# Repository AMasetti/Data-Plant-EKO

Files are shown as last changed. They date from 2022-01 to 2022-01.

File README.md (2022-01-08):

# Data Plant EKO

This project aims to have a plant pot fitted with electronics capable of monitoring a plant and alerting it’s owned if some parameter they see fit are out of certainty bounds. The captured data from the ambient and the plant is streamed to an MQTT Broker for later treatment if the MQTT option is enabled. This means the plant works as a stand alone unit monitoring and alerting the used via Neopixel lights or it can work in tandem with other systems streaming it’s data and listening for configuration changes

## Variables meassured

The following variables are measured and have a default lower and upper bound indicating the acceptable contritions that the plant need for it’s life to continue:

- Ambient Temperature [ºC]
    - Hardware: DHT11
    - Operating range: 0 - 50
    - Alerting range: <10 or >35

- Ambient Humidity [%]
    - Hardware: DHT11
    - Operating range: 0 - 100
    - Alerting range: <30 or >80

- Plant soil Temperature [ºC]
    - Hardware: NTC 3950
    - Operating range: :-20 - 105
    - Alerting range: <10 or >35

- Plant soil Humidity [%]
    - Hardware: HL-69
    - Operating range: 0 - 100
    - Alerting range: <30 or >80

- Ambient light [Lux]
    - Hardware: TEMP6000
    - Operating range: 0 -1000
    - Alerting range: 500

## Hardware used



The main CPU of the project is the ESP32 a microcontroller with integrated WiFi that is widely used in IoT projects. For fast prototyping and ease of repair the package used is the the Node MCU version of the ESP chip, which has breakout pins that can be easily soldered. 

The hardware used for the sensors is listed above with the corresponding variable measured.

No internal power supply is used in this project but the concept contemplates future improvements such as that. The electronics are powered by a micro usb connected directly to the Node MCU using a usb power plug as power source.

The soil sensors are fitted from under the pot and are isolated using hot glue to prevent water getting into the electronics. The ambient and light sensors are fitted on the side and top of the pot respectively. The Node MCU and Neopixel ring are located a the bottom of the pot. The pot on the other hand is made out of 3D printed transparent PLA which allows the Neopixel ring to light it out from the inside. This STLs files are provided in the Hardware folder of the project.

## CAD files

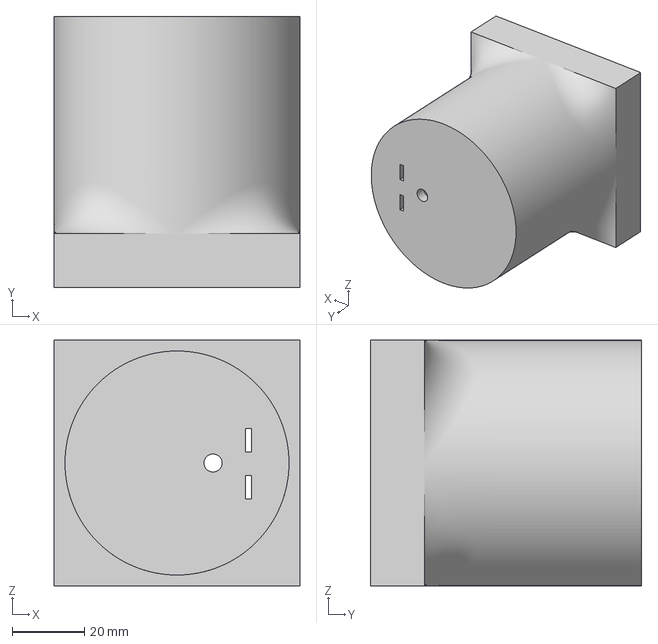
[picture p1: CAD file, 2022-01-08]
stls/MainPot.3mf
68.0 x 75.0 x 68.0 mm

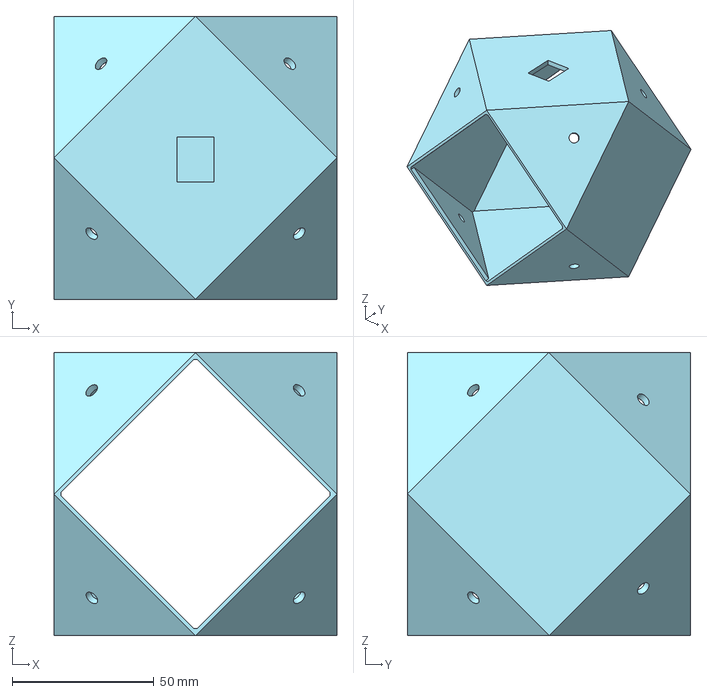
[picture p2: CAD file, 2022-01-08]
stls/CubeoctahedronShell.3mf
99.9 x 99.9 x 99.9 mm

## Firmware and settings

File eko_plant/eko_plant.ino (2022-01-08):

#include <Adafruit_Sensor.h>
#include <FastLED.h>
#include <DHT.h>
#include <WiFi.h>
#include <PubSubClient.h>
#include "secrets.h"

// MQTT Device ID definitions
#define DEVICE "eko"          // Device Name DataPlantEKO
#define ROOT "iotplant"       // MQTT Topic root

// Pin definitions
#define DHTPIN 26             // Digital pin connected to the DHT sensor
#define NUM_LEDS 8            // Number of LEDs in the strip
#define NEOPIN 25             // PWM Pin for the Neopixel ring
#define BRIGHTNESS  100       // Brightness of the LED strip
#define LIGHTSENSORPIN 39     // Ambient light sensor pin
#define SOILHUMPIN 36         // Soil humidity sensor pin

// Sensors definitions
#define DHTTYPE DHT11          // DHT 11 type of sensor in use (11, 21, 22)

// Client declarations
WiFiClient espClient;
PubSubClient client(espClient);
long lastMsg = 0;
char msg[100];
int value = 0;

// Hardware declarations
DHT dht(DHTPIN, DHTTYPE);
CRGB leds[NUM_LEDS];

// MQTT Topics definitions
String topic_root =  String(ROOT) + "/" + String(DEVICE);
// Data topic
String publish_data_str = topic_root + "/data";
const char* publish_data = publish_data_str.c_str();
// Configurations topic
String subs_config_str = topic_root + "/config";
const char* subs_config = subs_config_str.c_str();
// Neopixel status topic
String subs_neopixels_str = topic_root + "/neopixels";
const char* subs_neopixels = subs_neopixels_str.c_str();
// Reset alert topic
String publish_reset_string = topic_root + "/reset";
const char* publish_reset = publish_reset_string.c_str();

// NTP
const char* ntpServer = "pool.ntp.org";
unsigned long epochTime; 

// Plant configuration variables
bool enableMQTT = true;           // Sets the MQTT Client to ON by default
int sample_time = 500;            // Sample time in milliseconds
float minTempDHT = 0;             // Minimum temperature to be considered as a healthy plant (celsius)
float maxTempDHT = 50;            // Maximum temperature to be considered as a healthy plant (celsius)
float minHumDHT  = 0;             // Minimum humidity to be considered as a healthy plant (percentage)
float maxHumDHT  = 100;           // Maximum humidity to be considered as a healthy plant (percentage)
float minLight = 0;               // Minimum light to be considered as a healthy plant (percentage)
float maxLight = 100;             // Maximum light to be considered as a healthy plant (percentage)
float minSoilHum = 0;             // Minimum soil humidity to be considered as a healthy plant (percentage)
float maxSoilHum = 100;           // Maximum soil humidity to be considered as a healthy plant (percentage)
float minSoilTemp = 0;            // Minimum soil temperature to be considered as a healthy plant (celsius)
float maxSoilTemp = 50;           // Maximum soil temperature to be considered as a healthy plant (celsius)


unsigned long getTime() {
  time_t now;
  struct tm timeinfo;
  if (!getLocalTime(&timeinfo)) {
    //Serial.println("Failed to obtain time");
    return(0);
  }
  time(&now);
  return now;
}

void setup_wifi() {
  delay(10);
  // We start by connecting to a WiFi network
  Serial.println();
  Serial.print("Connecting to ");
  Serial.println(SSID);

  WiFi.begin(SSID, PASSWORD);

  while (WiFi.status() != WL_CONNECTED) {
    delay(500);
    Serial.print(".");
  }

  Serial.println("");
  Serial.println("WiFi connected");
  Serial.println("IP address: ");
  Serial.println(WiFi.localIP());
}

void callback(char* topic, byte* payload, unsigned int length) {
  Serial.print("Message arrived [");
  Serial.print(topic);
  Serial.print("] ");
  for (int i = 0; i < length; i++) {
    Serial.print((char)payload[i]);
  }
  Serial.println();

  if (String(topic) == String(subs_neopixels)) {
    // Switch on the LED if an 1 was received as first character
    if ((char)payload[0] == '1') {
//      fill_solid( leds, NUM_LEDS, CRGB::Black);
//      delay(50);
//      FastLED.show();
//      delay(50);
      // but actually the LED is on; this is because
      // it is active low on the ESP-01)
    } else {

//      fill_solid( leds, NUM_LEDS, CRGB::Blue);
//      delay(50);
//      FastLED.show();
//      delay(50);
    }
  }
}

void neo_wait() {
  // Flash LEDs in a circle with dimming brightness
  for (int i = 0; i < NUM_LEDS; i++) {
    leds[i] = CRGB::Blue;
    FastLED.show();
    delay(50);
    leds[i] = CRGB::Black;
    FastLED.show();
    delay(50);
  }
}

void neo_ok() {
  // pulsate the LEDs
  fill_solid( leds, NUM_LEDS, CRGB::Green);
  for (int i = 0; i < 100; i++) {
    FastLED.setBrightness(i);
    FastLED.show();
    delay(10);
  }
  fill_solid( leds, NUM_LEDS, CRGB::Black);
  FastLED.show();
  for (int i = 100; i > 0; i--) {
    FastLED.setBrightness(i);
    FastLED.show();
    delay(10);
  }
  fill_solid( leds, NUM_LEDS, CRGB::Black);
  FastLED.show();
}

void reconnect() {
  // Loop until we're reconnected
  while (!client.connected()) {
    Serial.print("Attempting MQTT connection...");
    // Attempt to connect
    if (client.connect("ESP32Client")) {
      Serial.println("connected");
      // Subscribe
      client.subscribe(subs_neopixels);
     client.subscribe(subs_config);
    } else {
      Serial.print("failed, rc=");
      Serial.print(client.state());
      Serial.println(" try again in 5 seconds");
      // Wait 5 seconds before retrying
      delay(5000);
    }
  }
}

void setup() {
  Serial.begin(115200);
  Serial.println("Configuring the device...");
  
  dht.begin();
  Serial.println("DHT11 Sensor configured on pin " + String(DHTPIN));
  
  FastLED.addLeds<NEOPIXEL, NEOPIN>(leds, NUM_LEDS);
  Serial.println("Neopixels configured on pin " + String(NEOPIN));

  setup_wifi();
  Serial.println("WiFi configured");

  if (enableMQTT) {
    client.setServer(MQTT_SERVER, 1883);
    client.setCallback(callback);
    Serial.println("MQTT Client configured");
  }

  configTime(-3, 0, ntpServer);
  Serial.println("NTP configured");

  Serial.println("Configuration complete");
   delay(5000);
  neo_wait();
}

void loop() {
  if (!client.connected()) {
    reconnect();
  }
  client.loop();

  long now = millis();
  if (now - lastMsg > sample_time) {
    lastMsg = now;
    
    // Read DHT temperature
    float dht_temp = dht.readTemperature();
    if (isnan(dht_temp)) {
      Serial.println("Failed to read from DHT sensor!");
    }

    // Read DHT humidity
    float dht_hum = dht.readHumidity();
    if (isnan(dht_hum)) {
      Serial.println("Failed to read from DHT sensor!");
    }

    // Read soil humidity in percentage
    int soil_hum = analogRead(SOILHUMPIN);
    soil_hum = map(soil_hum, 4095, 0, 0, 100);

    // Read light level
    float reading = analogRead(LIGHTSENSORPIN);
    float lux = map(reading, 0, 4095, 0, 1000);


    // Touch Sensor
    bool touch = touchRead(32) < 70;
    if (touch) {
      neo_ok();
    }

    Serial.println("------------------------------------------------------");
    Serial.print("DHT Temp Sensor: ");
    Serial.println(dht_temp);
    Serial.print("DHT Humidity Sensor: ");
    Serial.println(dht_hum);
    Serial.print("Soil Humidity Sensor: ");
    Serial.println(soil_hum);
    Serial.print("Light Sensor: ");
    Serial.println(lux);
    Serial.print("Touch Sensor: ");
    Serial.println(touch);
    
    Serial.print("Sent: ");

    // Create the payload to send
    sprintf(msg, "{\"dht_temp\":%2f, \"dht_hum\":%2f,\"light\":%2f,\"soil_hum\":%d}", dht_temp, dht_hum, lux, soil_hum);
    client.publish(publish_data, msg);

    epochTime = getTime();
    Serial.print("Epoch Time: ");
    Serial.println(epochTime);
  }
}
